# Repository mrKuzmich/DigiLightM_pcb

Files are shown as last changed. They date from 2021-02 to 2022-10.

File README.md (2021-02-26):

# DigiLight-M
DigiLight-M is a project of digital light organ with automat of light effects. This project based on [DigiLight](https://cxem.net/sound/light/light127.php) project of user [AVR](https://cxem.net/profile/17379).

This part of the project contains the schematic of the device itself and PCB. The source codes of the ATMega32 microcontroller firmware in the C language you can see in another part of the project [DigiLightM_firmware](https://github.com/mrKuzmich/DigiLightM_firmware).

## Whats new
1. Changed the power suply of the digital and analog parts of circuit;
2. Added line-in and microphone input with electronic source selection;
3. SD Card adapter replaced with direct connection of MicroSD Card;
4. Redesigned PCB. 

## Appearance
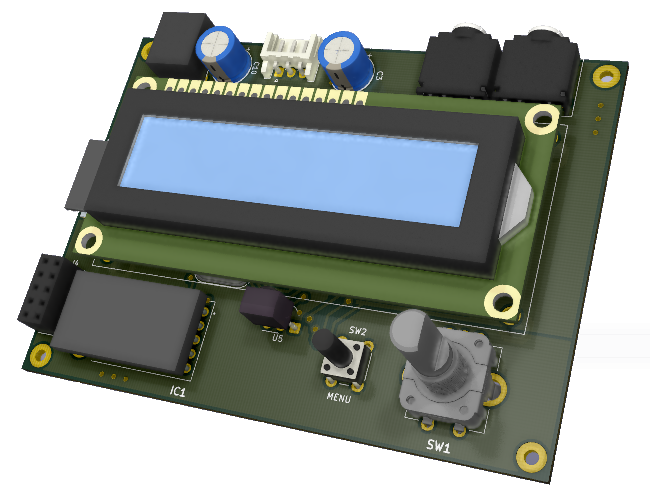
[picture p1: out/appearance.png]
Appearance


## Schematic
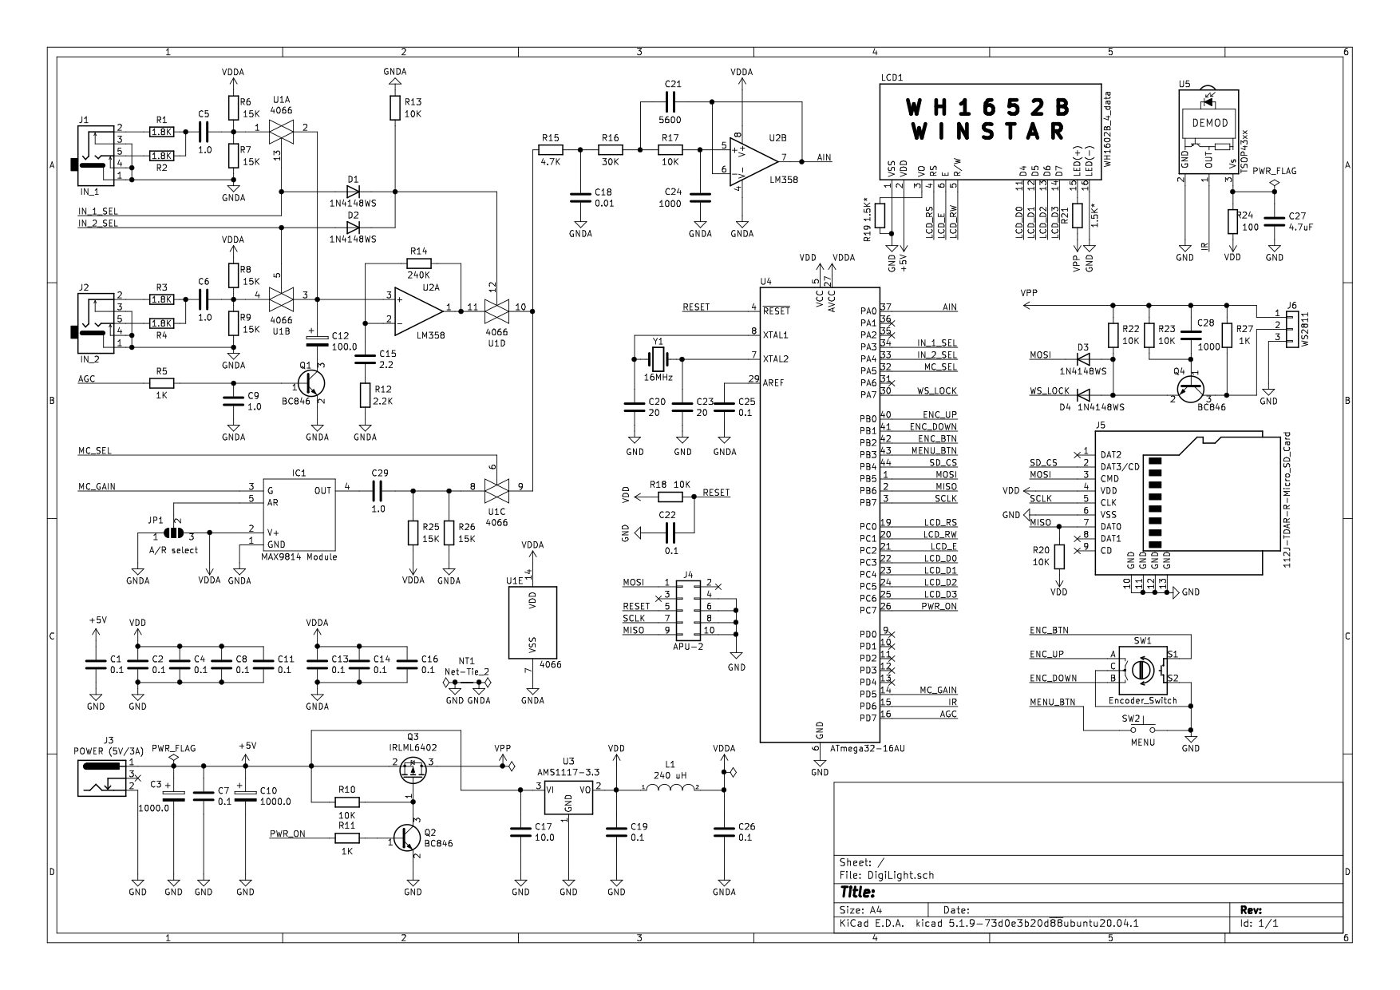
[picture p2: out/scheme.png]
Schematic


## Firmware
[DigiLightM_firmware](https://github.com/mrKuzmich/DigiLightM_firmware) repository.

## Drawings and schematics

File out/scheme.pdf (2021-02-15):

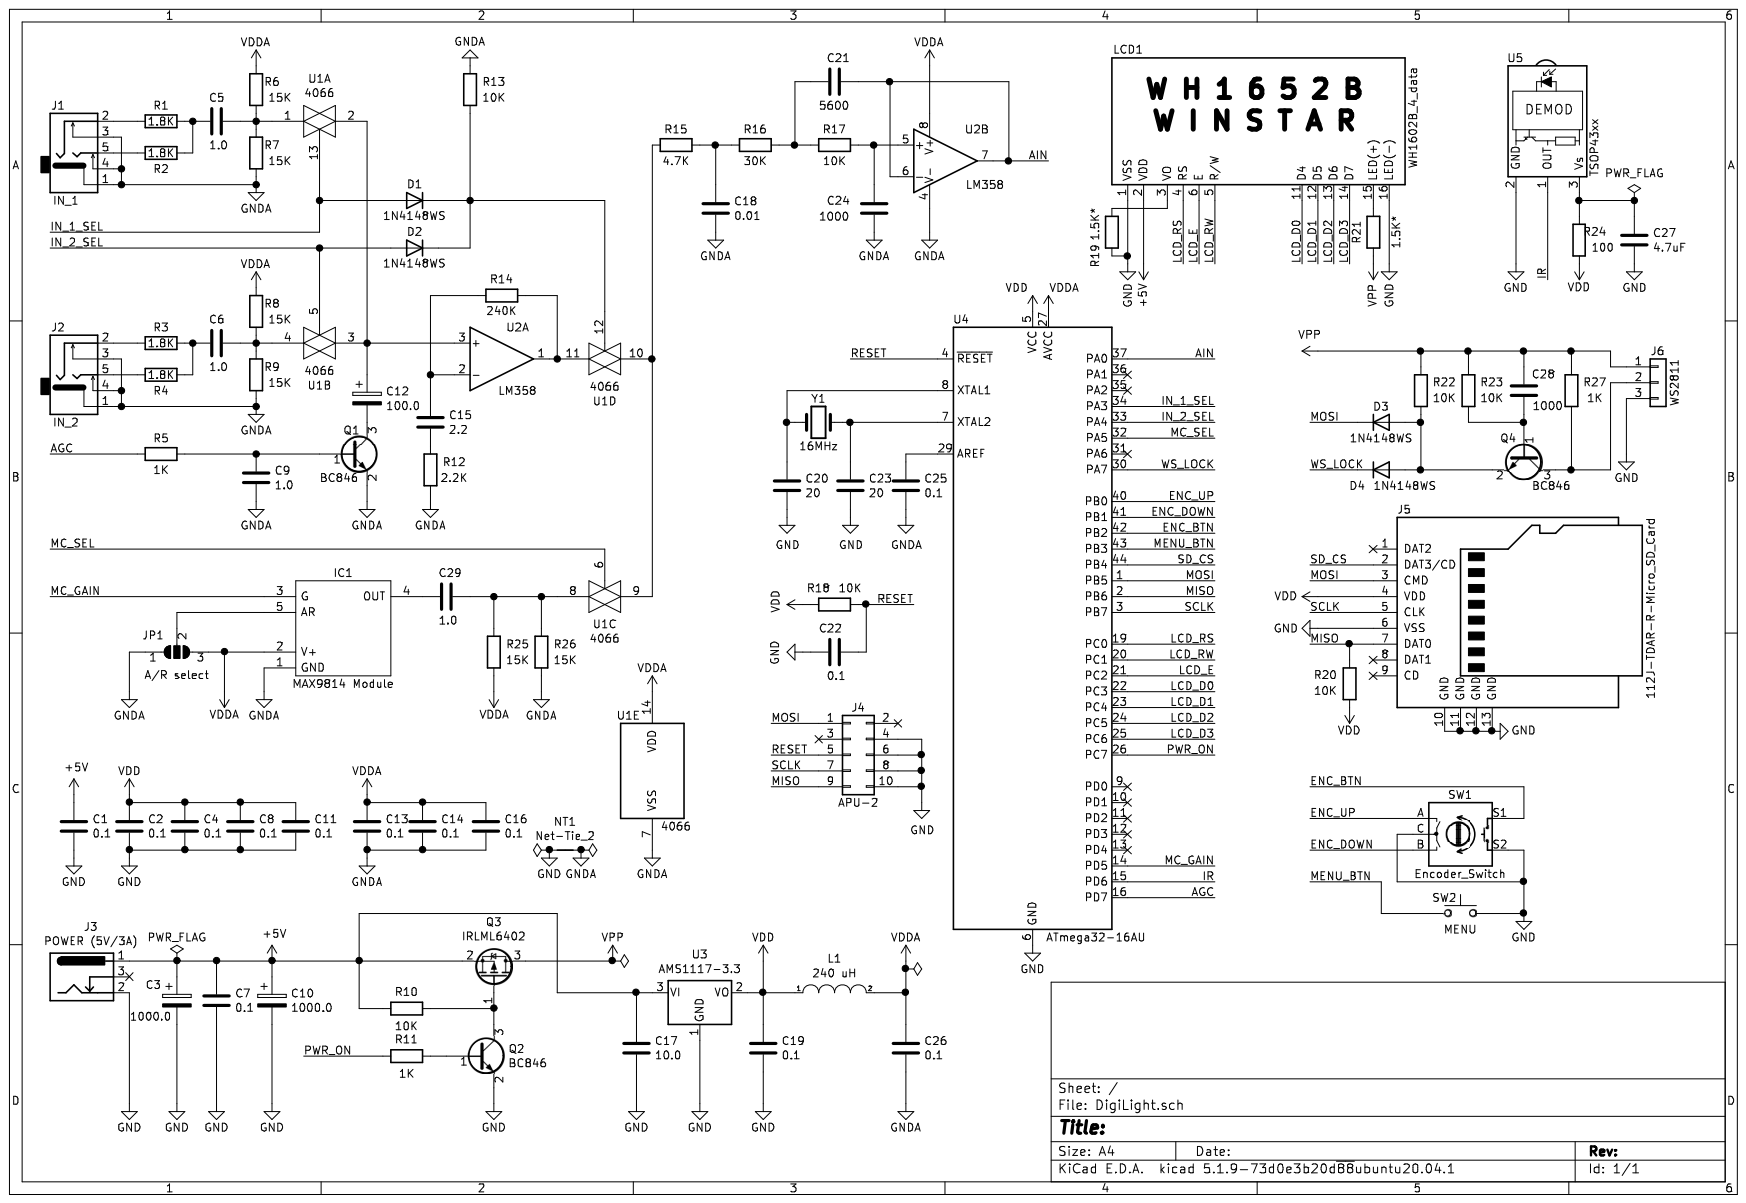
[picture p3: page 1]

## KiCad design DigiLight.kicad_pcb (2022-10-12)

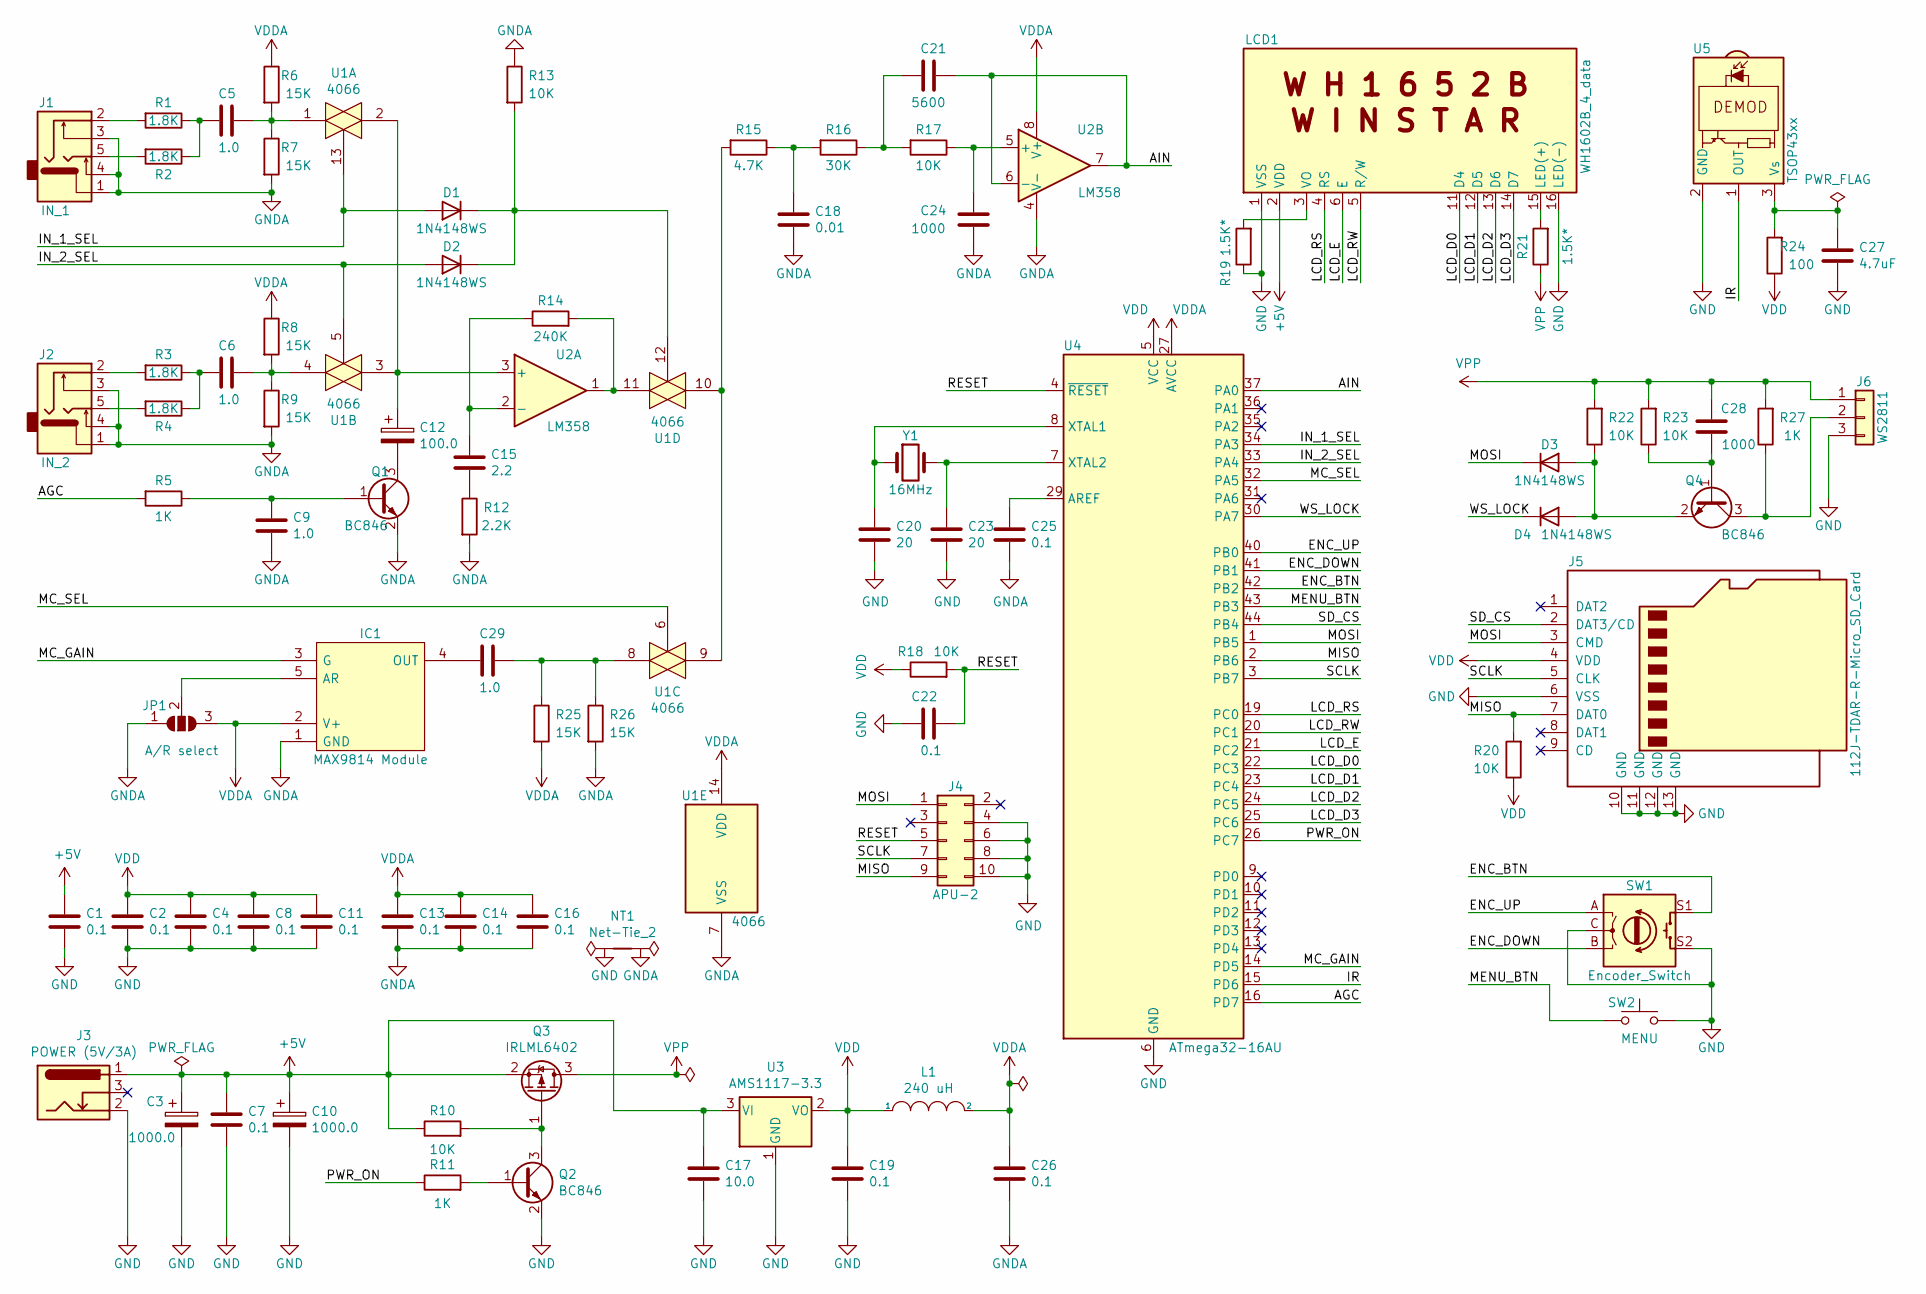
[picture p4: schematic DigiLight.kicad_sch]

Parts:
C1, C2, C4, C7, C8, C11, C13, C14, C16, C19, C22, C25, C26: 0.1; C_1206_3216Metric
C3, C10: 1000.0; CP_Radial_D8.0mm_P5.00mm
C5, C6, C9, C29: 1.0; C_1206_3216Metric
C12: 100.0; CP_EIA-3528-21_Kemet-B_Pad1.50x2.35mm_HandSolder
C15: 2.2; C_1206_3216Metric
C17: 10.0; C_1206_3216Metric
C18: 0.01; C_1206_3216Metric
C20, C23: 20; C_1206_3216Metric
C21: 5600; C_1206_3216Metric
C24, C28: 1000; C_1206_3216Metric
C27: 4.7uF; C_1206_3216Metric
D1, D2, D3, D4: 1N4148WS; D_SOD-323
IC1: MAX9814 Module; 1713; Manufacturer_Part_Number 1713; Mouser Part Number 485-1713
J1: IN_1; PJ-307
J2: IN_2; PJ-307
J3: POWER (5V/3A); DC-044
J4: APU-2; PinSocket_2x05_P2.54mm_Vertical
J5: 112J-TDAR-R-Micro_SD_Card; 112JTDARR
J6: WS2811; JST_EH_S3B-EH_1x03_P2.50mm_Horizontal
JP1: A/R select; SolderJumper-3_P1.3mm_Open_RoundedPad1.0x1.5mm
L1: 240 uH; L_1210_3225Metric
LCD1: WH1602B_4_data; WC1602A_4_data
NT1: Net-Tie_2; NetTie-2_SMD_Pad2.0mm
Q1, Q2, Q4: BC846; SOT-23
Q3: IRLML6402; SOT-23
R1, R2, R3, R4: 1.8K; R_1206_3216Metric
R5, R11, R27: 1K; R_1206_3216Metric
R6, R7, R8, R9, R25, R26: 15K; R_1206_3216Metric
R10, R13, R17, R18, R20, R22, R23: 10K; R_1206_3216Metric
R12: 2.2K; R_1206_3216Metric
R14: 240K; R_1206_3216Metric
R15: 4.7K; R_1206_3216Metric
R16: 30K; R_1206_3216Metric
R19, R21: 1.5K*; R_1206_3216Metric
R24: 100; R_1206_3216Metric
SW1: Encoder_Switch; PEC11R4220FS0024
SW2: MENU; SW_PUSH_6mm_H13mm
U1: 4066; SOIC-14_3.9x8.7mm_P1.27mm
U2: LM358; SOIC-8_3.9x4.9mm_P1.27mm
U3: AMS1117-3.3; SOT-223-3_TabPin2
U4: ATmega32-16AU; TQFP-44_10x10mm_P0.8mm
U5: TSOP43xx; Vishay_MOLD-3Pin
Y1: 16MHz; Crystal_HC49-4H_Vertical

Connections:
+5V: C1.1, C3.1, C7.1, C10.1, C17.1, J3.1, LCD1.2 (VDD), Q3.2 (S), R10.1, U3.3 (VI)
/AGC: R5.2, U4.16 (PD7)
/AIN: C21.1, U2.6 (-), U2.7, U4.37 (PA0)
/ENC_BTN: SW1.S1, U4.42 (PB2)
/ENC_DOWN: SW1.B, U4.41 (PB1)
/ENC_UP: SW1.A, U4.40 (PB0)
/IN_1_SEL: D1.2 (A), U1.13, U4.34 (PA3)
/IN_2_SEL: D2.2 (A), U1.5, U4.33 (PA4)
/IR: U4.15 (PD6), U5.1 (OUT)
/LCD_D0: LCD1.11 (D4), U4.22 (PC3)
/LCD_D1: LCD1.12 (D5), U4.23 (PC4)
/LCD_D2: LCD1.13 (D6), U4.24 (PC5)
/LCD_D3: LCD1.14 (D7), U4.25 (PC6)
/LCD_E: LCD1.6 (E), U4.21 (PC2)
/LCD_RS: LCD1.4 (RS), U4.19 (PC0)
/LCD_RW: LCD1.5 (R/W), U4.20 (PC1)
/MC_GAIN: IC1.3 (G), U4.14 (PD5)
/MC_SEL: U1.6, U4.32 (PA5)
/MENU_BTN: SW2.1, U4.43 (PB3)
/MISO: J4.9, J5.7 (DAT0), R20.2, U4.2 (PB6)
/MOSI: D3.1 (K), J4.1, J5.3 (CMD), U4.1 (PB5)
/PWR_ON: R11.1, U4.26 (PC7)
/RESET: C22.1, J4.5, R18.2, U4.4 (~RESET)
/SCLK: J4.7, J5.5 (CLK), U4.3 (PB7)
/SD_CS: J5.2 (DAT3/CD), U4.44 (PB4)
/WS_LOCK: D4.1 (K), U4.30 (PA7)
GND: C1.2, C2.2, C3.2, C4.2, C7.2, C8.2, C10.2, C11.2, C17.2, C19.2, C20.2, C22.2, C23.2, C27.2, J3.2, J4.4, J4.6, J4.8, J4.10, J5.6 (VSS), J5.10 (GND), J5.11 (GND), J5.12 (GND), J5.13 (GND), J6.3, LCD1.1 (VSS), LCD1.16 (LED(-)), NT1.1, Q2.2 (E), R19.1, SW1.C, SW1.S2, SW2.2, U3.1 (GND), U4.6 (GND), U4.18 (GND), U4.28 (GND), U4.39 (GND), U5.2 (GND)
GNDA: C9.2, C13.2, C14.2, C16.2, C18.2, C24.2, C25.2, C26.2, IC1.1 (GND), J1.1, J1.3, J1.4, J2.1, J2.3, J2.4, JP1.1 (A), NT1.2, Q1.2 (E), R7.2, R9.2, R12.2, R13.1, R26.2, U1.7 (VSS), U2.4 (V-)
unnamed: C5.1, R6.2, R7.1, U1.1
unnamed: C5.2, R1.1, R2.1
unnamed: C6.1, R8.2, R9.1, U1.4
unnamed: C6.2, R3.1, R4.1
unnamed: C9.1, Q1.1 (B), R5.1
unnamed: C12.1, U1.2, U1.3, U2.3 (+)
unnamed: C12.2, Q1.3 (C)
unnamed: C15.1, R14.1, U2.2 (-)
unnamed: C15.2, R12.1
unnamed: C18.1, R15.1, R16.2
unnamed: C20.1, U4.8 (XTAL1), Y1.1
unnamed: C21.2, R16.1, R17.2
unnamed: C23.1, U4.7 (XTAL2), Y1.2
unnamed: C24.1, R17.1, U2.5 (+)
unnamed: C25.1, U4.29 (AREF)
unnamed: C27.1, R24.2, U5.3 (Vs)
unnamed: C28.1, Q4.1 (B), R23.1
unnamed: C29.1, R25.1, R26.1, U1.8
unnamed: C29.2, IC1.4 (OUT)
unnamed: D1.1 (K), D2.1 (K), R13.2, U1.12
unnamed: D3.2 (A), D4.2 (A), Q4.2 (E), R22.1
unnamed: IC1.5 (AR), JP1.2 (C)
unnamed: J1.2, R1.2
unnamed: J1.5, R2.2
unnamed: J2.2, R3.2
unnamed: J2.5, R4.2
unnamed: J6.2, Q4.3 (C), R27.1
unnamed: LCD1.3 (VO), R19.2
unnamed: LCD1.15 (LED(+)), R21.2
unnamed: Q2.1 (B), R11.2
unnamed: Q2.3 (C), Q3.1 (G), R10.2
unnamed: R14.2, U1.11, U2.1
unnamed: R15.2, U1.9, U1.10
VDD: C2.1, C4.1, C8.1, C11.1, C19.1, J5.4 (VDD), L1.1, R18.1, R20.1, R24.1, U3.2 (VO), U4.5 (VCC), U4.17 (VCC), U4.38 (VCC)
VDDA: C13.1, C14.1, C16.1, C26.1, IC1.2 (V+), JP1.3 (B), L1.2, R6.1, R8.1, R25.2, U1.14 (VDD), U2.8 (V+), U4.27 (AVCC)
VPP: C28.2, J6.1, Q3.3 (D), R21.1, R22.2, R23.2, R27.2

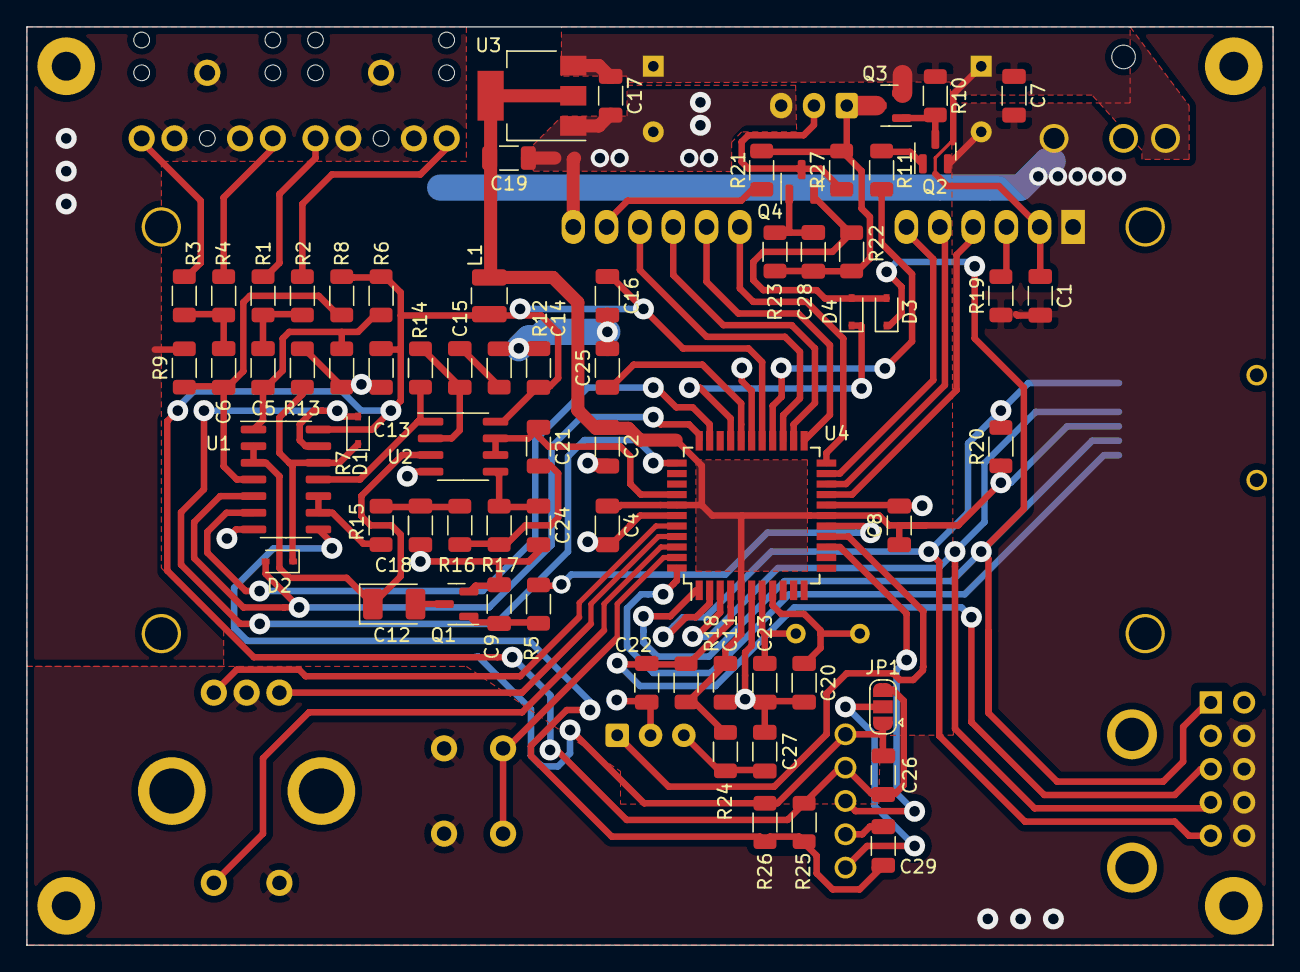
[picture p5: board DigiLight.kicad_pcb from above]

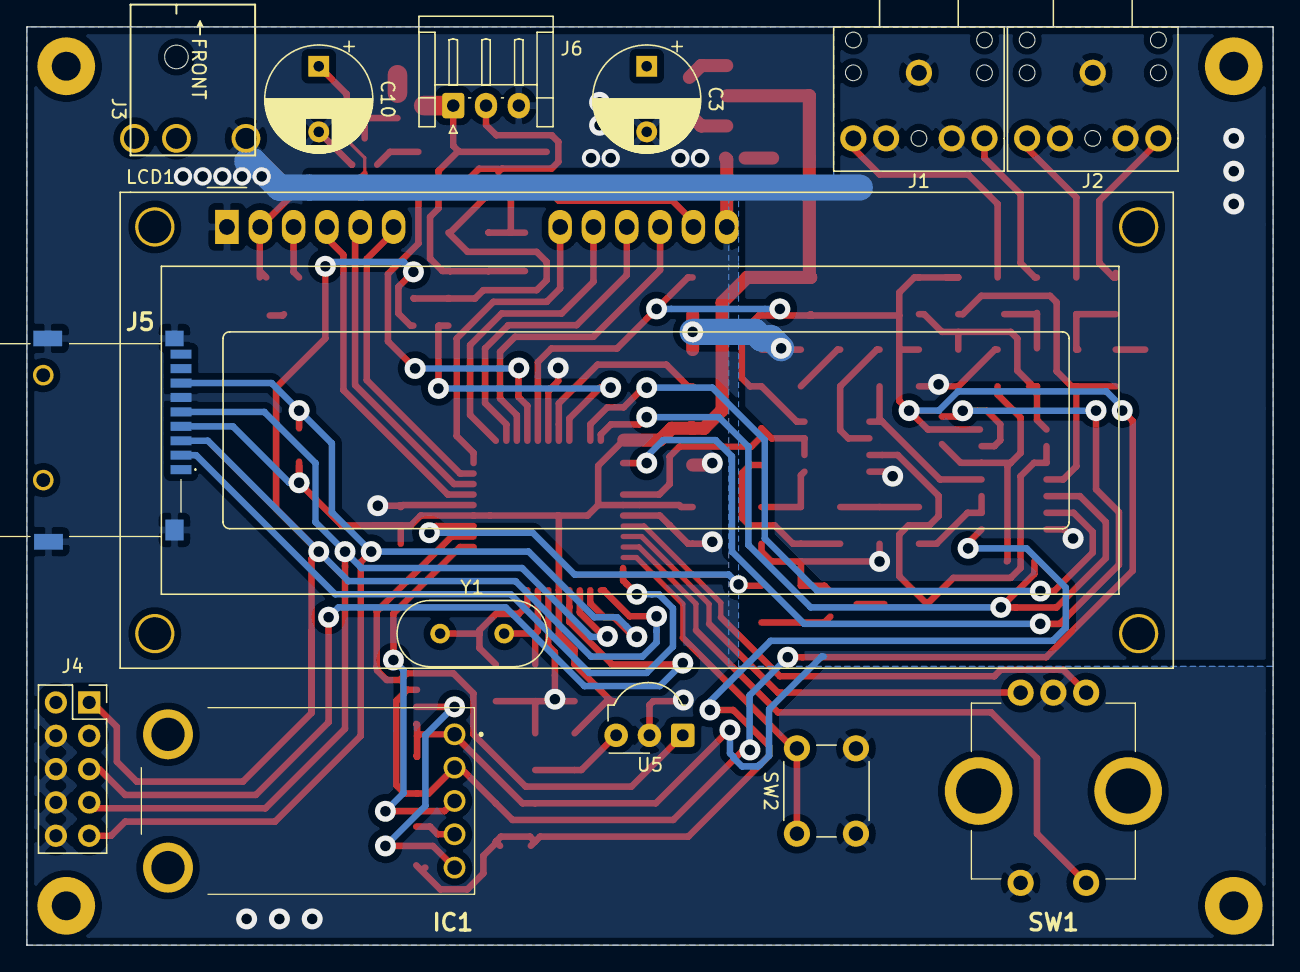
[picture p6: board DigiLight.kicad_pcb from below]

Board: 2 copper layers, 95.0 x 70.0 mm, 83 parts (15 on the bottom side), 64 nets.

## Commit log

2020-03-19 Init commit. Circuit of DigiLight with two lines inputs and microphone input.
    [DigiLight.kicad_pcb, DigiLight.sch]
2020-03-23 Refactoring input circuit, reassigned MC pins, replace LCD footprint, create PCB template
    [DigiLight.kicad_pcb, DigiLight.sch]
2020-04-08 Tracing PCB finished
    [DigiLight.kicad_pcb, DigiLight.sch]
2020-04-19 Final trace
    [DigiLight.kicad_pcb, DigiLight.sch]
2020-04-19 Recalculated 3rd order Sallen-Key Low-pass filter
    [DigiLight.sch]
2020-11-13 Adding mofels of dc-044 connector and wc1602 display
2020-11-13 Update models, pcb build finish, change output key.
    [DigiLight.kicad_pcb, DigiLight.sch]
2020-11-16 Changed C28 capcity
    [DigiLight.sch]
2020-11-16 Changed footprint of microphone module, added bias voltage to microphone signal, changed power suply of LCD.
    [DigiLight.kicad_pcb, DigiLight.sch]
2021-02-15 Changed output switch on schematic and pcb
    [DigiLight.kicad_pcb, DigiLight.sch]
2021-02-15 Update README.md
    Add schematic
2022-10-12 Migrating to Kicad 6.0. Removed external links.
    [DigiLight.kicad_pcb, DigiLight.kicad_sch]
2022-11-02 Power connector replaced to USB type-c
    [DigiLight.kicad_sch]
